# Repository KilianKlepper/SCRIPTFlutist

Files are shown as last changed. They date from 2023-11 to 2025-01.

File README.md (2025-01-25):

# The Stained Flutist
>
> Bringing Light to Nostalgia

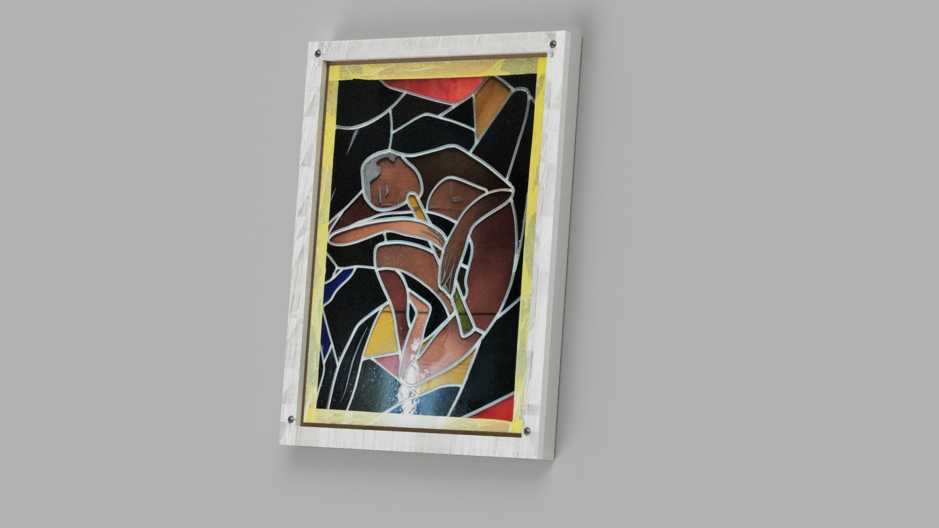
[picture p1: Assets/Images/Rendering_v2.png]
Flutist in the Stained glass


## Overview

Welcome to the Stained Flutist, where we're turning an old colored glass window into a dazzling wall art piece that lights up like a conzert! This project is more than just LEDs and nostalgia; it's an RGB-tastic journey into the sentimental side of life. The window, once a part of a house filled with laughter and memories, is now getting its moment in the spotlight.

## Features

- Sentimental Illumination: We're not just throwing lights on a window; we're telling a story—nostalgia with a side of technicolor.

- RGB Glow: Bring the right emotion into the unique old frame. Play with different light settings and effect.

- Control: Use the haptic control pannel or impress your friends while controlling the window via the smartphone

- App Magic: challanging for us but easy to use. Turn the Flutist on and off or controll differen color settings

- Frame: Holding all in place with the sophisticated frame extension. Converting the LED spots into gradient lighting via frosted glass and a white backcover to get the most out of the light.

## Project Structure

### Mechanical

- Frame conzept
- Fusion 360 Files
- Purchased parts

### Electrical

- Schematic
- GPIO Connection to different features

### Software

- ESP32 and its necessary libarys
- main software
- features software

### App

- Flutter based BLE Controll app

## Troubleshooting

The first test run on 26.11.23 was bombastic. However, we gained the following findings:

- The distance from the LEDs to the frosted glass is too small (2cm) this must be increased (3.5cm)

- therefore a frame must also be integrated

- an RGB effect of continuous full-surface colors is the best effect

- Light performance should be sufficient but 2-3 more meeters would be nice

- The screws must become longer

- The frame color was changed to white

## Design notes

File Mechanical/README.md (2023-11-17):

# Mechanical: The Stained Fluist
>
> Frame the Sentimental Illumination

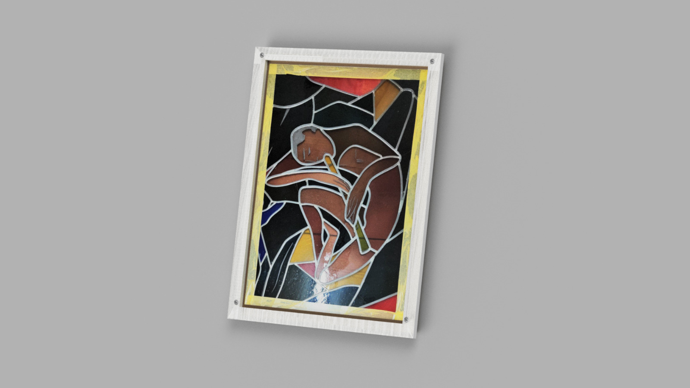
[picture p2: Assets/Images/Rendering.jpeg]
Fluist in the Stained glass


## Overview

In the dazzling world of the Stained Fluist, the Mechanical folder plays a pivotal role in bringing the project to life. Here, we dive into the physical components that make up our nostalgic light show.

### Dimensions

Overall dimensions from the Window rebuild in Fusion 360
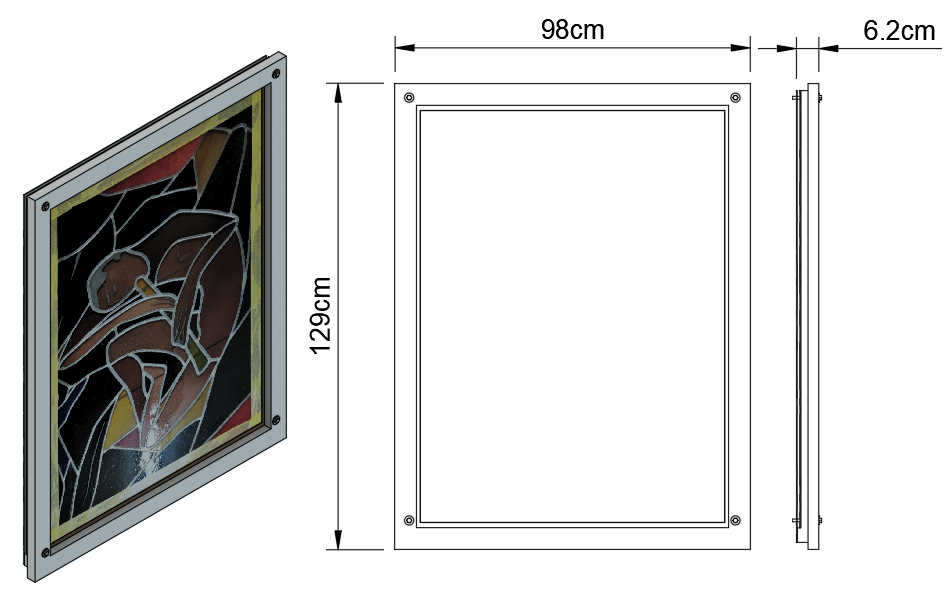
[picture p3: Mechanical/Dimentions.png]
Frame Drawing of the Window


### Mounting Conzept

Holding all together with M8 Screws
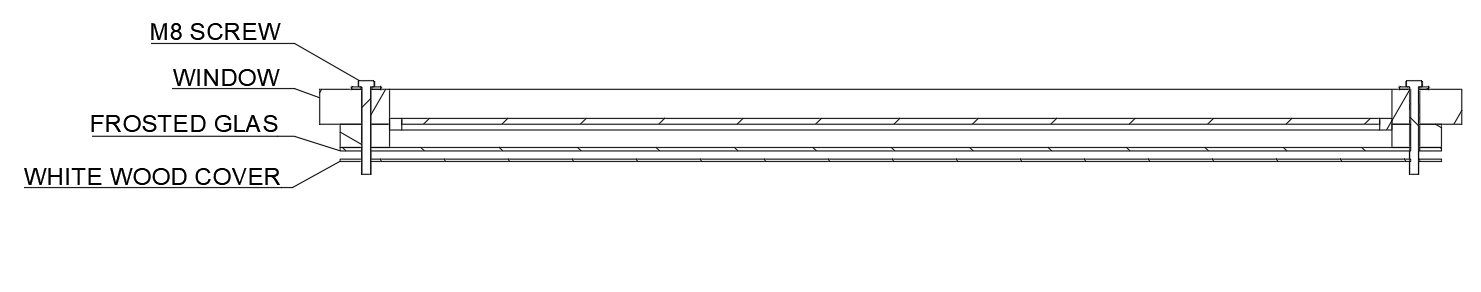
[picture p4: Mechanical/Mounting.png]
Sectional view of the Mouting Conzept


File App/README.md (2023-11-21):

# App: The Stained Fluist
>
> Visual the madic

Fluist in the Stained glass

## Overview

In the palm of your hand lies the magic wand for the Stained Fluist! The App folder introduces you to the BLE-powered mobile app, giving you control over the RGB spectacle right from your fingertips.

## Setup:
Phone: Einstellung/Entwickleroptionen/USB-Debugging

## Features

Librarys:

- [Flutter Blue](https://pub.dev/packages/flutter_blue) - current BLE lib but not stable
- [Flutter Reactive BLE](https://pub.dev/packages/flutter_reactive_ble) - maybe change to this
- [Color Picker](https://pub.dev/packages/flutter_colorpicker)

Future:

- [Animations](https://pub.dev/packages/animations)
-

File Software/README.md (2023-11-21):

# Software: The Stained Fluist
>
> Hack the canvas

Fluist in the Stained glass

## Overview

Enter the virtual realm of the Stained Fluist! In the Software folder, we unravel the lines of code that make the magic happen. From controlling LEDs to synchronizing colors, it's all about turning the window into a programmable canvas.

## Features
## Display
> Libraries: Adafruit_SSD1306 library and Adafruit_GFX library.

## RGB
> Libraries: FastLED and [DriverModule](https://forum.mysensors.org/topic/5670/fastled-library-and-rgb-led-strip-driver-module/2)

## BLE
> Libraries: Included in Aurduino

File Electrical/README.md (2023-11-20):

# Electrical: The Stained Fluist
>
> Power the Glow

Fluist in the Stained glass

## Overview

Welcome to the electrifying side of the Stained Fluist! In the Electrical folder, we unravel the mysteries behind powering up our RGB spectacle and making it blink, glow, and maybe even dance a little.

## Features

- Power Control: The level of Voltages
- MCU: ESP32 our brain
- RGB: WS28111 DC 12V 36W
- ON/OFF: For those who like it simple
- CapTouch Control: You can't see it, but feel if
- OLED Display: But why?
- RESET: Just in case

### Power Control

The used RGB strips require 12V input. The Power Control circuit controls two states of power.
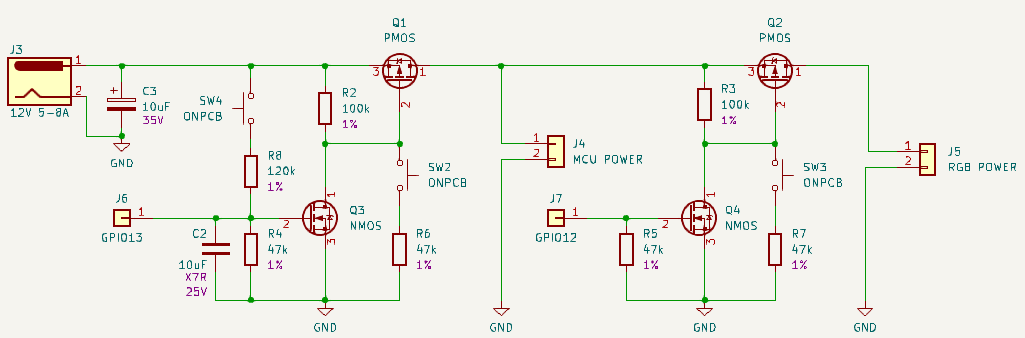
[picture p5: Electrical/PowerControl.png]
Power Controll schemactic

The Input is a AC230V DC12V power supply unit connected to the Frame.
The First High-Side Switch will control the power to the Buck-Converte used from the ESP32 without a HIGH signal the ESP32 will be in shutdown. The secound High-Side Switch will controll the Power to the RGB strips. This may be needed to reduce standby current.

### ESP32 WROOM

ESP32WROOM Pinout
<https://randomnerdtutorials.com/esp32-pinout-reference-gpios/>

| **Feature** | **GPIO** | **STATE** |
|:---|:---|---:|
| **POWER CONTROL** | | |
| MCU POWER |  GPIO12 | HIGH for power |
| RGB POWER |  GPIO13 | HIGH for power |
| | | |
| **BUTTONS:** | | |
| ON OFF | GPIO27(39) | active LOW |
| CAP WHITE | GPIO33(36) | active HIGH |
| CAP YELLOW | GPIO32(34) | active HIGH |
| CAP ORANGE | GPIO35 | active HIGH |
| VIB MOTOR | GPIO26 | HIGH for power |
| | | |
| **DISPLAY:** | | |
| DISP SCL | GPIO22 | PWM |
| DISP SDA | GPIO21 | PWM |
| | | |
| **RGB Data:** | | |
| RGB_0_M | GPIO23 | PWM |
| RGB_1_M | GPIO25 | PWM |
| RGB_2_M | GPIO19 | PWM |
| RGB_3_M | GPIO18 | PWM |
| RGB_4_M | GPIO17 | PWM |
| RGB_5_M | GPIO16 | PWM |
| RGB_6_M | GPIOxx(27) | PWM |
| RGB_7_M | GPIOxx(33) | PWM |
| RGB_8_M | GPIOxx(32) | PWM |
| RGB_9_M | GPIOxx(4) | PWM |
| | | |
| **IDEAS:** | | |
| IR-RECIEVER | GPIOxx() | |

### RGB

Model: [BTF-12V-30L-W](https://www.ebay.de/itm/222352737598?hash=item33c541853e:g:NmAAAOSwHORb4p8T)

Works with 3V3 Data in Signal

### ON OFF Button

Momentary button with Pull-Up to 3V3



### Cap Sensors

Module: [TTP-223](https://www.epitran.it/ebayDrive/datasheet/23.pdf)



3 Buttons to control RGB brightness and color type (longpress) / effect (shot press)

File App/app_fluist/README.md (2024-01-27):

# app_fluist

A new Flutter project.

## Getting Started

This project is a starting point for a Flutter application.

A few resources to get you started if this is your first Flutter project:

- [Lab: Write your first Flutter app](https://docs.flutter.dev/get-started/codelab)
- [Cookbook: Useful Flutter samples](https://docs.flutter.dev/cookbook)

<<<<<<< HEAD
In the Android settings You need to add the following permissions to your AndroidManifest.xml file:

```dart
    <uses-permission android:name="android.permission.BLUETOOTH_SCAN" android:usesPermissionFlags="neverForLocation" />
    <uses-permission android:name="android.permission.BLUETOOTH_CONNECT" />
    <uses-permission android:name="android.permission.ACCESS_FINE_LOCATION" android:maxSdkVersion="30" />
    <uses-permission android:name="android.permission.ACCESS_COARSE_LOCATION" android:maxSdkVersion="30" />
```

More details can be found in the [ReactiveBle-Git-Repo](https://github.com/PhilipsHue/flutter_reactive_ble)

### Get Packages

to get all used Packages to run the app just click `Get Packages` in the upper right corne in the `pubspec.yaml` file or run the following to install missing packages.

```terminal
    flutter pub get
```

## App

We are starting the app development with no glue.

Actualle we just use the example code from ReactiveBle and modify it till ti fits our needs. We achive this with tiers and the help of ChatGPT.
First we esteplish the connection. This happens eather manually or automathacly when starting the app.

After scanning for the better half The ESP named Flutter we try to connect with this fellow. After the connection is assteblished. We can than send RGB and PowerOnOff information with BLE.

### Characteristic

The written data into the Characteristic looks like following which will be converted into:

```c
    New Message (Hex): 1ff6d2117 -> eARGB: 1 255 109 33 23
```

| data  | Effects | Alpha | Red | Green | Blue |
| ----- | --- | --- | --- | --- | --- |
| eARGB | 1 | 255 | 109 | 33 | 23 |
| | | | | | |
| eARGB | 0 - 9 | 0 - 255 | 0 - 255 | 0 - 255 | 0 - 255 |
| | | | | | |

The Effects are defined like following:

```c
    enum rgbEffect
    {
        OFF,             // OFF   - set off state as an effect to simplify
        BASIC,           // BASIC - soid one filled color
        FADE,            // FADE  - a fade thorugh the hue colors
        RAINBOW,         // RNBW  - rainbow effect hole spectrum
        RAINBOWGLITTER,  // RGGL  - rainbow with some random glitter 
        CONFETTI,        // CNFT  - rainbow colors but random
        RUNNINGLIGHT,    // RUNL  - running light from 0 to 100
        JUGGLE,          // JGL   - colored dots, weaving in and out in sync
        SINELON,         // SNLN  - colored dot sweeping back and forth
        STATIONARY       // STAT  - local effect triggerd by esp button
    };
```

```mermaid
graph TD

subgraph Initialization
  A[Initialize App] -->|Start Scan| B(Scan for Devices)
  B -->|Device Found| C{Is FLUIST?}
  C -- Yes --> D[Stop Scan]
  D --> E(Connect to FLUIST)
  E -->|Connected| F{Connected?}
end

subgraph ManualInteraction
  G(Button: Scan) -->|Start Scan| B
  G -->|Connect to Device| E
  G -->|Update RGB| I(Update RGB)
end

subgraph MainInteraction
  H(Button: PowerOnOff) -->|Update RGB| I
  I -->|Update RGB| J(Button: Color Picker / Effects)
end

subgraph BLECommunication
  J -->|Update RGB| I
  I -->|Write Characteristic| L(ESP FLUIST)
end

```
=======
For help getting started with Flutter development, view the
[online documentation](https://docs.flutter.dev/), which offers tutorials,
samples, guidance on mobile development, and a full API reference.
>>>>>>> parent of 4fb1247 (:memo: add documentatoin to app readme in APP_FLUIST)

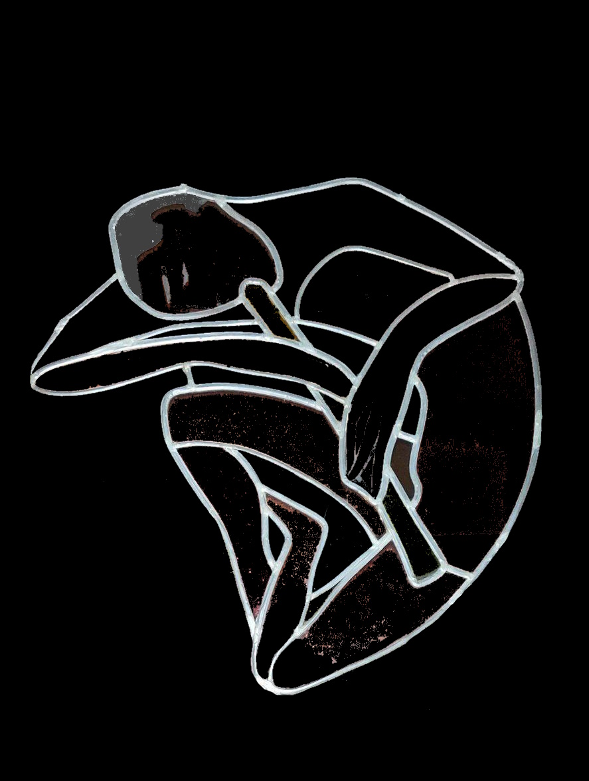
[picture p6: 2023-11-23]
Assets/Images/Black&White.jpg

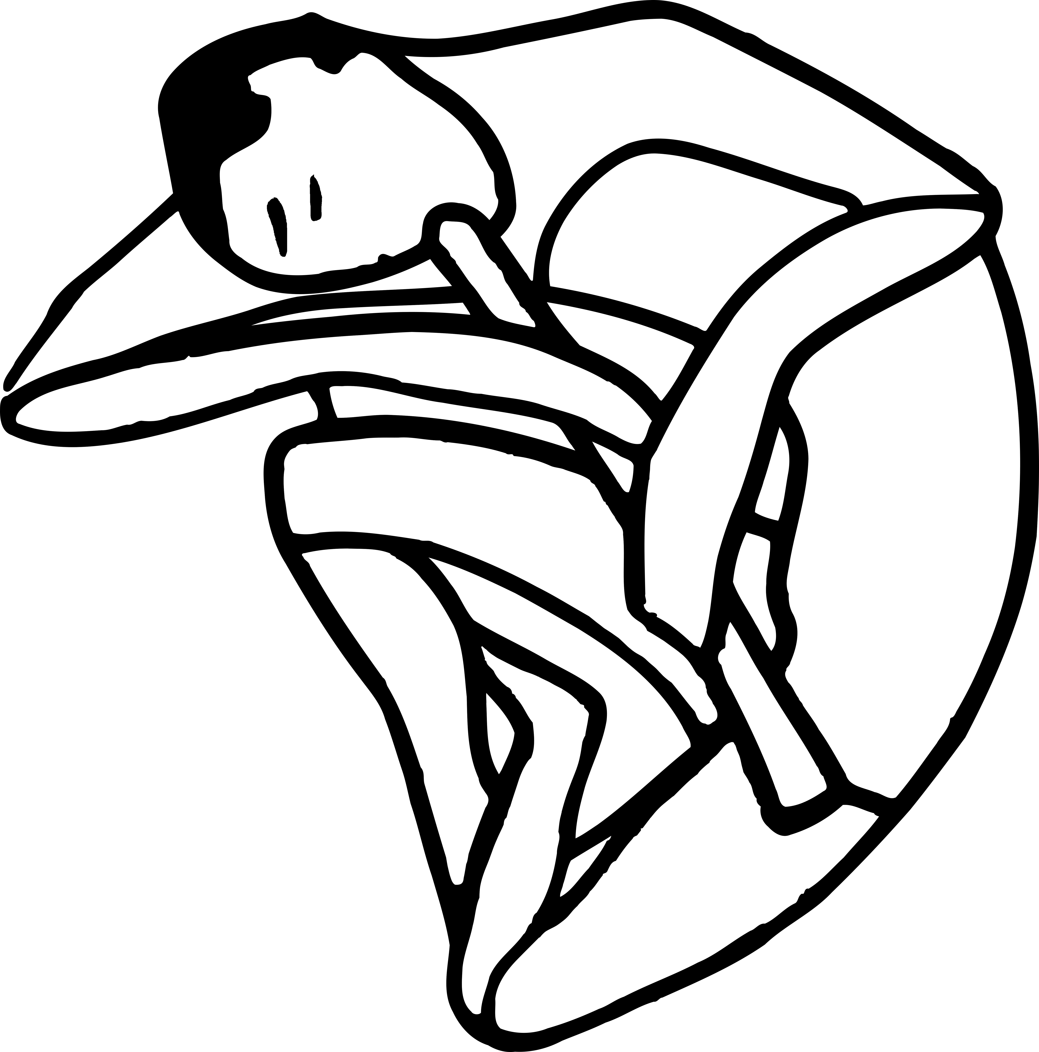
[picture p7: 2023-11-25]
Assets/Images/White&Black.png

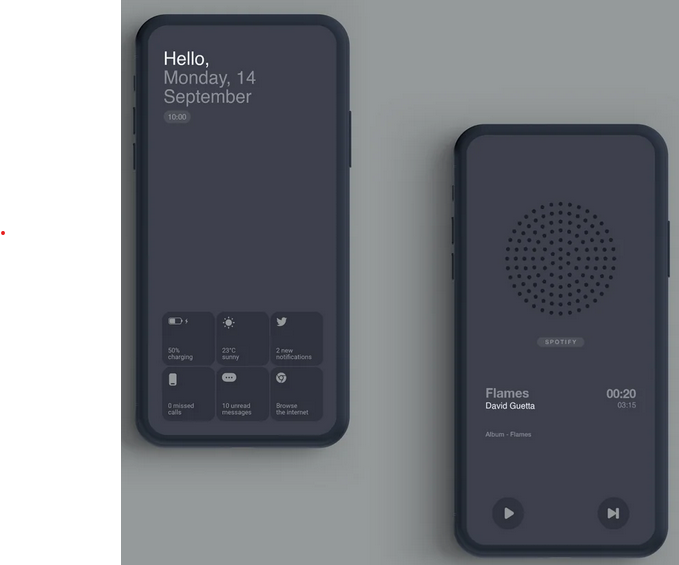
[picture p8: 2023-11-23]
App/Assets/Example_1.png

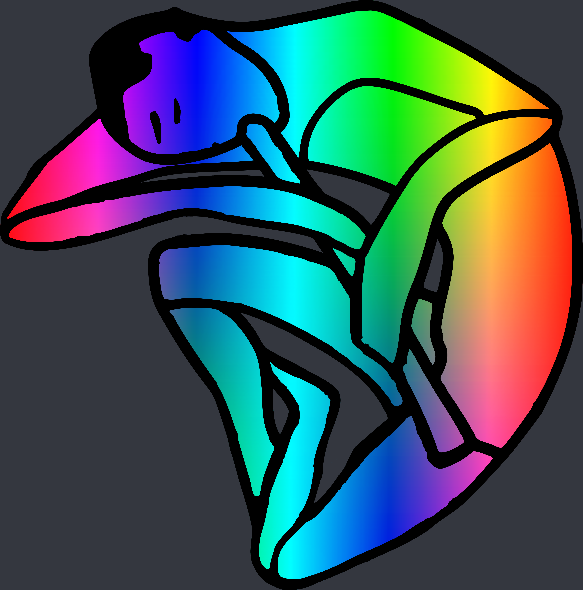
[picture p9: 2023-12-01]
App/app_fluist/assets/rainbow.png

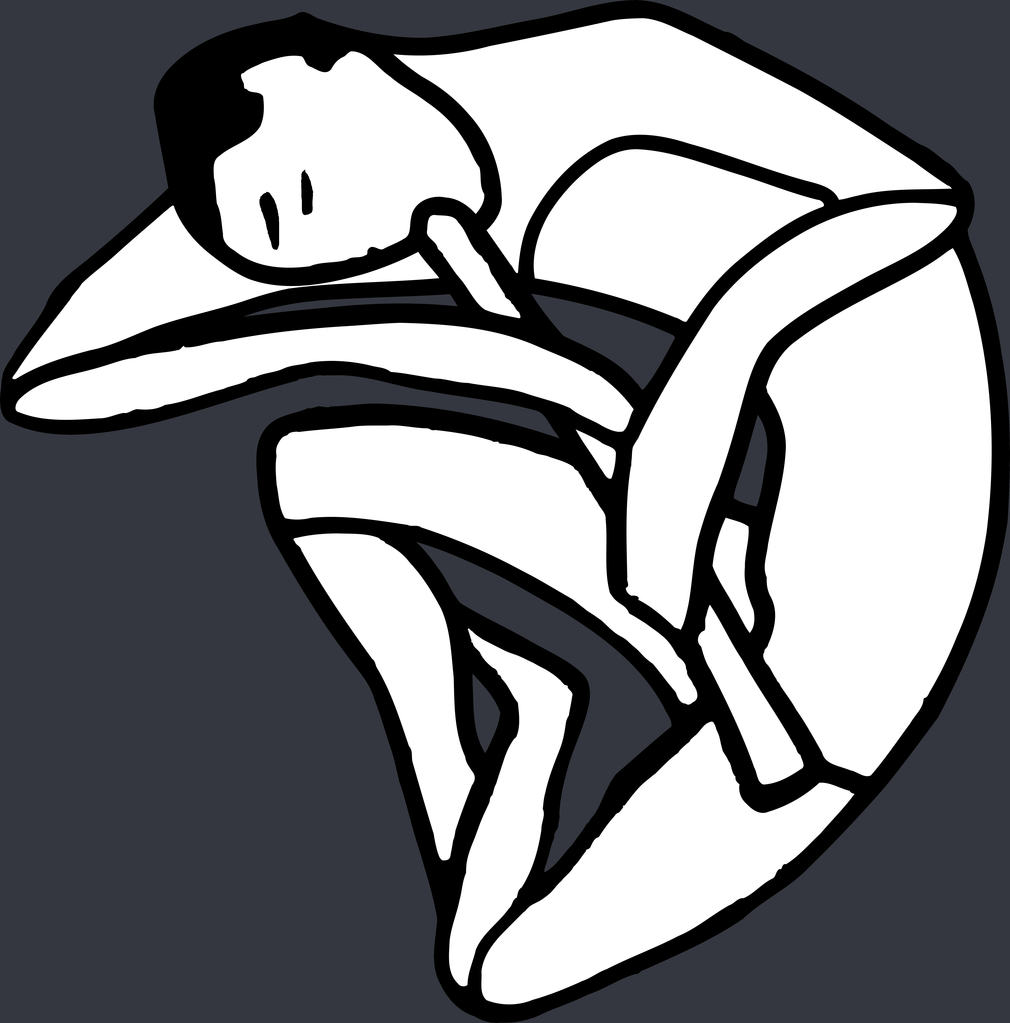
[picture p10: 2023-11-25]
App/app_fluist/assets/outline.png

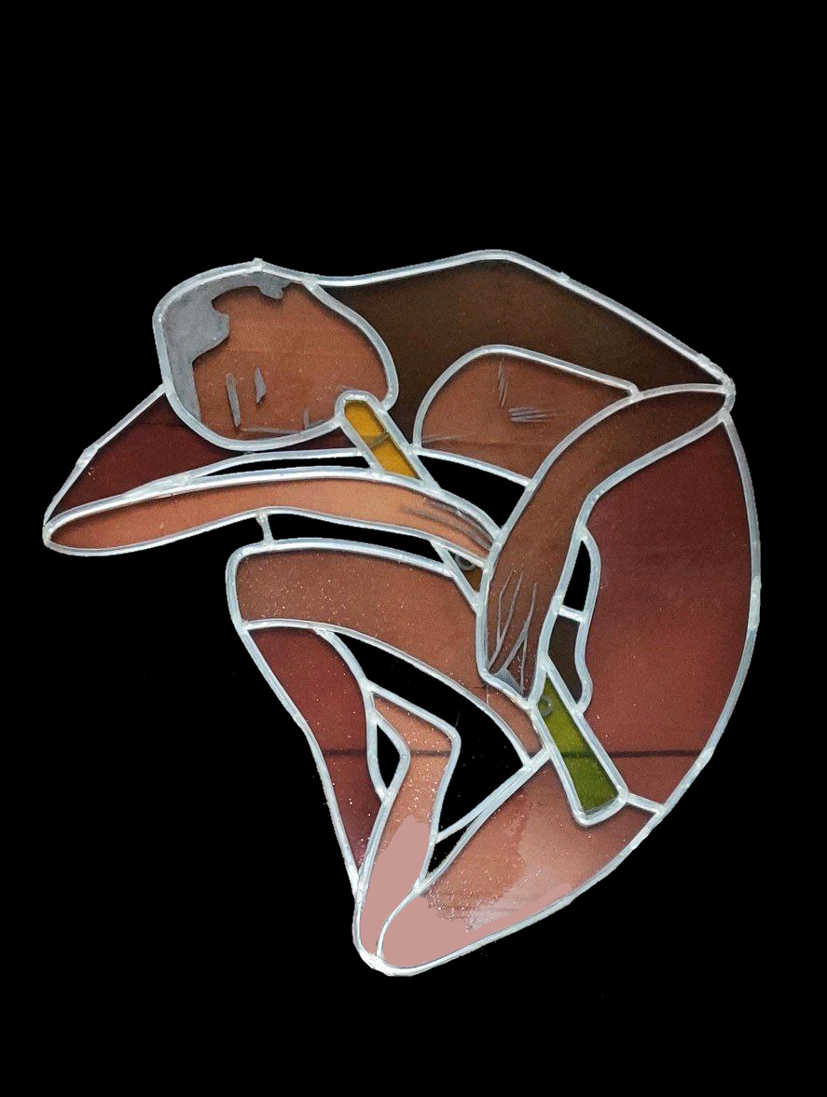
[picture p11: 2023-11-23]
Assets/Images/Fluist.jpg

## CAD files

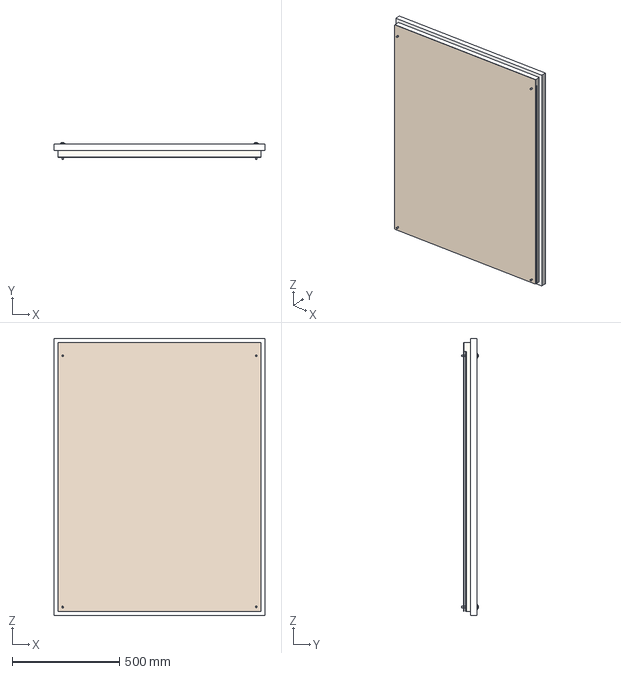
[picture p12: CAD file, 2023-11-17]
Mechanical/Fluist.step
981.0 x 80.3 x 1289.0 mm
FensterRekonstruktion
Screws x 4

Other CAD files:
Mechanical/Fluist.f3z

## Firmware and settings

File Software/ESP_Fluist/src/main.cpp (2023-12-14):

#include <Arduino.h>
#include <interface.h>
#include <display.h>
#include <ble.h>
#include <rgb.h>

rgbEffect fluistEffect_test = FADE;
int fluistEffect = OFF;
int fluistBrightness = 0;
int fluistSpeed = 10;
int fluistHue = 0;

enum state_machine
{
  FLUIST_ON,
  FLUIST_OFF
};
state_machine state = FLUIST_OFF;

void setup()
{
  Serial.begin(115200);
  initInterface();
  // initDisplay();
  // initRGB();
  initBLE();

  Serial.println("Initializing:............ DONE");
}

void loop()
{
  // Update Devices#
  bleDisconnect();
  bleConnect();
  // Update OLED

  switch (state)
  {
  case FLUIST_OFF:
    // Update Display
    // displayOnOff_Status(get_RGB_Power_state());

    // Transition Function
    if (toogle_Power_state() || get_valueEFFECT() != OFF)
    {
      Serial.print("StateMachine set to:......");
      state = FLUIST_ON;
      digitalWrite(RGB_POW, true);
      Serial.println("ON");
    }
    break;
  case FLUIST_ON:
    // Update Display
    // displayBLE_Status(get_connectionState());
    // displayARGBValue(get_valueEFFECT(), get_valueALPHA(), get_r(), get_g(), get_b());
    // displayOnOff_Status(get_RGB_Power_state());
    // displayCapSense_Status(get_CapSense_Up_state(), get_CapSense_Down_state(), get_CapSense_Effect_state());
    // Update RGB
    fluistEffect = get_valueEFFECT();
    fluistBrightness = get_valueALPHA();

    updateRGBeffect(fluistEffect, fluistBrightness, fluistSpeed, fluistHue);

    // Button Update
    if (get_CapSense_Up_state())
    {
      write_valueEFFECT(9);
      fluistHue++;
      delay(10);
    }
    if (get_CapSense_Down_state())
    {
      write_valueALPHA(5);
      delay(10);
    }
    if (toogle_Effect_state())
    {
      write_valueEFFECT(random(2, 6));
    }
    vibration_feedback(get_CapSense_Up_state() || get_CapSense_Down_state() || get_CapSense_Effect_state());

    // Transition Function
    if (get_valueEFFECT() == OFF)
    {
      Serial.print("StateMachine set to:......");
      state = FLUIST_OFF;
      write_valueEFFECT(OFF);
      digitalWrite(RGB_POW, false);
      // displayClear();
      Serial.println("OFF");
    }
    break;

  default:
    break;
  }
  delay(10);
}

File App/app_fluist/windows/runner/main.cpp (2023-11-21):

#include <flutter/dart_project.h>
#include <flutter/flutter_view_controller.h>
#include <windows.h>

#include "flutter_window.h"
#include "utils.h"

int APIENTRY wWinMain(_In_ HINSTANCE instance, _In_opt_ HINSTANCE prev,
                      _In_ wchar_t *command_line, _In_ int show_command) {
  // Attach to console when present (e.g., 'flutter run') or create a
  // new console when running with a debugger.
  if (!::AttachConsole(ATTACH_PARENT_PROCESS) && ::IsDebuggerPresent()) {
    CreateAndAttachConsole();
  }

  // Initialize COM, so that it is available for use in the library and/or
  // plugins.
  ::CoInitializeEx(nullptr, COINIT_APARTMENTTHREADED);

  flutter::DartProject project(L"data");

  std::vector<std::string> command_line_arguments =
      GetCommandLineArguments();

  project.set_dart_entrypoint_arguments(std::move(command_line_arguments));

  FlutterWindow window(project);
  Win32Window::Point origin(10, 10);
  Win32Window::Size size(1280, 720);
  if (!window.Create(L"app_fluist", origin, size)) {
    return EXIT_FAILURE;
  }
  window.SetQuitOnClose(true);

  ::MSG msg;
  while (::GetMessage(&msg, nullptr, 0, 0)) {
    ::TranslateMessage(&msg);
    ::DispatchMessage(&msg);
  }

  ::CoUninitialize();
  return EXIT_SUCCESS;
}

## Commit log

2023-11-17 :books: Starting documentation
    [Fluist.f3z, Fluist.step]
2023-11-20 :construction: working on ESP32 Software Features
2023-11-27 :construction: implement state machine with simple button control
2023-11-29 :bug: BLE connection not possible - device not found
    [main.cpp]
2023-12-14 :sparkles: increased ble power to max +9dbm
2024-01-27 🔀 merge to main
